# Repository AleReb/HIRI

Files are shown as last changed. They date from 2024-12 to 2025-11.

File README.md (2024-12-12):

# HIRI
"Proyecto HIRI usa ESP32 C3 para recolectar datos ambientales con PMS5003ST y transmitirlos vía BLE. Los datos se guardan en una SD. NeoPixel muestra estados y la pantalla OLED es solo para depuración. Monitorea batería y entra en deep sleep si es necesario. Diseñado para proyectos IoT. se adjuntan el diseño del shield"
# Proyecto HIRI usando BLE - Versión 0.02

## Descripción
Este proyecto utiliza un **ESP32 C3** para recolectar datos de un sensor **Plantower PMS5003ST** y transmitirlos vía BLE. Además, incorpora una pantalla OLED para depuración y un NeoPixel para indicadores visuales. Los datos se guardan en una tarjeta SD en formato CSV para facilitar su análisis.

## Características principales

1. **Comunicación BLE**:
   - Recepción de datos de latitud y longitud desde una aplicación móvil vía BLE.
   - Envío de datos del sensor al dispositivo móvil conectado.

2. **Gestión de Datos**:
   - Almacenamiento en una tarjeta SD en formato CSV.
   - Identificación única de sesiones usando timestamps.

3. **Indicadores visuales**:
   - **NeoPixel** para estados BLE:
   - azul para el inicio.
   - violeta para error.
   - cambia de verde a rojo segun el material particulado (segun norma chilena siendo 50ppm el nivel peligroso).
   - parpadea 3 veces si esta desconetado.
   - cuando guarda en la micro sd se atenua la luz un poco.
     
   - **OLED** para mostrar información de depuración como voltaje de batería, estado BLE, y valores de los sensores.

4. **Gestión de batería**:
   - Monitoreo del voltaje de la batería.
   - Entrada en modo deep sleep si el voltaje es inferior al umbral.

5. **Gestión de versiones**:
   - Registro de cambios y versiones en el encabezado del código.

6. **Tabla de IDs predefinidos**:
   - Asociación de IDs de dispositivo con datos predefinidos.

## Requisitos

### Hardware
- **ESP32 C3**
- Sensor **Plantower PMS5003ST**
- Pantalla OLED con interfaz I2C
- NeoPixel
- Tarjeta SD y lector compatible
- Fuente de alimentación con monitoreo de voltaje

### Librerías
Incluye las siguientes librerías en tu entorno de desarrollo (Arduino IDE o equivalente usando la placa esp32 c3 dev con la version 2.0.17 de la gestion de placas):

- `Adafruit_NeoPixel`
- `esp_adc_cal`
- `SoftwareSerial`
- `Wire`
- `SPI`
- `SD`
- `U8g2lib`
- `TimeLib`
- `BLEDevice`

## Instalación

1. **Clonar el repositorio**:
   ```bash
   git clone https://github.com/tu-usuario/proyecto-hiri.git
   cd proyecto-hiri
   ```

2. **Configurar el entorno de desarrollo**:
   - Abre el archivo principal en tu IDE.
   - Configura los pines según tu hardware.

3. **Carga del código**:
   - Conecta el ESP32 C3 a tu computadora.
   - Carga el código al ESP32 C3 desde tu IDE.

## Uso

1. Conecta la fuente de alimentación al ESP32 C3.
2. Abre la aplicación móvil para interactuar con el dispositivo vía BLE.
3. Observa el estado de conexión y los datos en la pantalla OLED.
4. Los datos recolectados se guardarán automáticamente en la tarjeta SD.

## Contribuir

1. Realiza un fork del proyecto.
2. Crea una nueva rama para tu característica o corrección de error:
   ```bash
   git checkout -b nueva-caracteristica
   ```
3. Haz commit de tus cambios:
   ```bash
   git commit -m "Añadida nueva característica"
   ```
4. Envía tus cambios:
   ```bash
   git push origin nueva-caracteristica
   ```
5. Abre un Pull Request en el repositorio principal.

## Licencia
Este proyecto está licenciado bajo la Licencia MIT. Consulta el archivo `LICENSE` para más detalles.

## Contacto
Si tienes preguntas o sugerencias, no dudes en contactar a:
**Alejandro Rebolledo. arebolledo@udd.cl**

## Registro de Cambios

### Versión 0.02.1
- Ajustes en la lógica de guardado de datos.
- Implementación de recepción de datos BLE (latitud, longitud, etc.).
- Mejoras en los indicadores NeoPixel y mensajes OLED.

### TO DO
- Mejorar la gestion y registro de dispostivos.
- Mejorar la forma de guardar los datos en el csv.

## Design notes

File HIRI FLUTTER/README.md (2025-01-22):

# hiri

Hiri app for device communication and configuration using BLE

## Getting Started

This project is a starting point for a Flutter application.

A few resources to get you started if this is your first Flutter project:

- [Lab: Write your first Flutter app](https://docs.flutter.dev/get-started/codelab)
- [Cookbook: Useful Flutter samples](https://docs.flutter.dev/cookbook)

For help getting started with Flutter development, view the
[online documentation](https://docs.flutter.dev/), which offers tutorials,
samples, guidance on mobile development, and a full API reference.

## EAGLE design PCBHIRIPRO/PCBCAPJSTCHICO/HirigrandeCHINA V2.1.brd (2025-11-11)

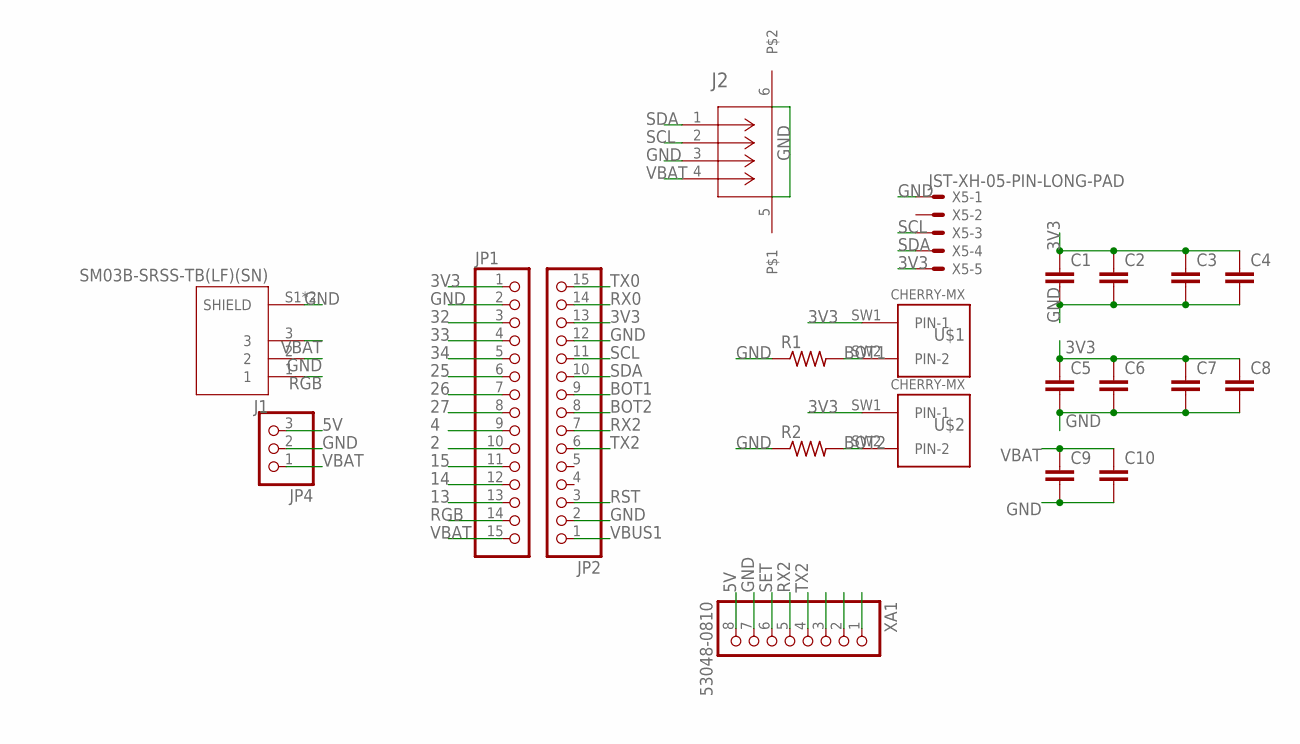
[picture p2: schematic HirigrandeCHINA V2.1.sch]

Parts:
C1, C2, C3, C4, C5, C6, C7, C8, C9, C10: C-EUC4532; C4532
J1: SM03B-SRSS-TB(LF)(SN); JST_SM03B-SRSS-TB(LF)(SN)
J2: SM04B-SRSS-TB; CONN_SM04B-SRSS-TB_JST
JP1, JP2: PINHD-1X15; 1X15
JP4: PINHD-1X3; 1X03
R1, R2: R-US_0204/7; 0204/7
U$1, U$2: CHERRY-MX
X5: JST-XH-05-PIN-LONG-PAD; JST-XH-05-PACKAGE-LONG-PAD
XA1: 53048-0810; MOLEX_53048-0810

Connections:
2: JP1.10
3V3: C1.1, C2.1, C3.1, C4.1, C5.1, C6.1, C7.1, C8.1, JP1.1, JP2.13, U$1.SW1 (PIN-1), U$2.SW1 (PIN-1), X5.5
4: JP1.9
5V: JP4.3, XA1.8
13: JP1.13
14: JP1.12
15: JP1.11
25: JP1.6
26: JP1.7
27: JP1.8
32: JP1.3
33: JP1.4
34: JP1.5
BOT1: JP2.9, R1.2, U$1.SW2 (PIN-2)
BOT2: JP2.8, R2.2, U$2.SW2 (PIN-2)
GND: C1.2, C2.2, C3.2, C4.2, C5.2, C6.2, C7.2, C8.2, C9.2, C10.2, J1.2, J1.S1 (SHIELD), J1.S2 (SHIELD), J2.3, J2.5, J2.6, JP1.2, JP2.2, JP2.12, JP4.2, R1.1, R2.1, X5.1, XA1.7
RGB: J1.1, JP1.14
RST: JP2.3
RX0: JP2.14
RX2: JP2.7, XA1.5
SCL: J2.2, JP2.11, X5.3
SDA: J2.1, JP2.10, X5.4
SET: XA1.6
TX0: JP2.15
TX2: JP2.6, XA1.4
VBAT: C9.1, C10.1, J1.3, J2.4, JP1.15, JP4.1
VBUS1: JP2.1

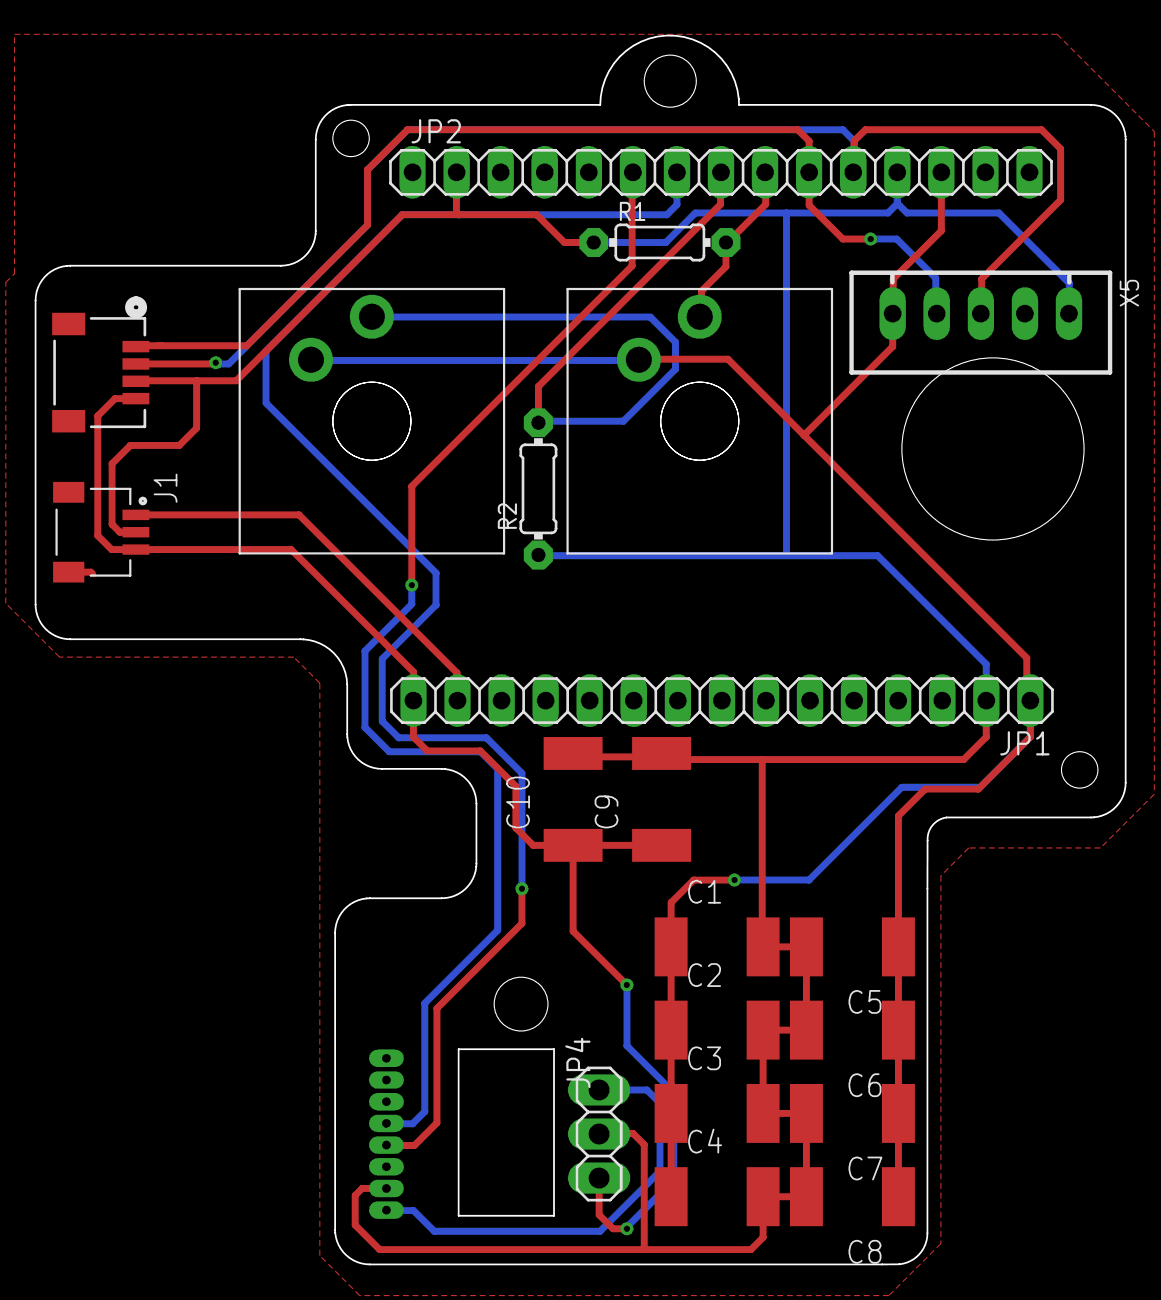
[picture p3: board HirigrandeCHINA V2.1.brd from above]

Board: 2 copper layers, 62.8 x 70.8 mm, 21 parts (0 on the bottom side), 11 nets.

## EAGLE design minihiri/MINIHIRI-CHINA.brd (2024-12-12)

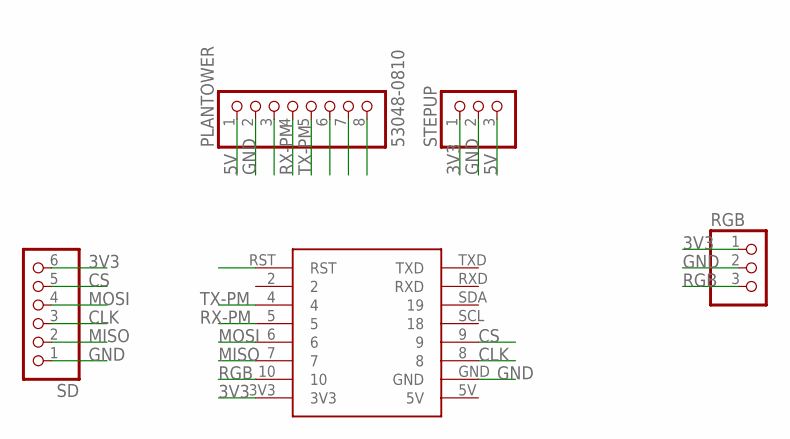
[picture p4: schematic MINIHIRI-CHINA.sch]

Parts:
PLANTOWER: 53048-0810; MOLEX_53048-0810
RGB: PINHD-1X3; 1X03
SD: PINHD-1X6; 1X06
STEPUP: PINHD-1X3; 1X03
U$2: LILYGOPLUSMINI; LILYGO-PADS

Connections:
3V3: RGB.1, SD.6, STEPUP.1, U$2.3V3
5V: PLANTOWER.1, STEPUP.3
CLK: SD.3, U$2.8
CS: SD.5, U$2.9
GND: PLANTOWER.2, RGB.2, SD.1, STEPUP.2, U$2.GND
MISO: SD.2, U$2.7
MOSI: SD.4, U$2.6
RGB: RGB.3, U$2.10
RX-PM: PLANTOWER.4, U$2.5
TX-PM: PLANTOWER.5, U$2.4

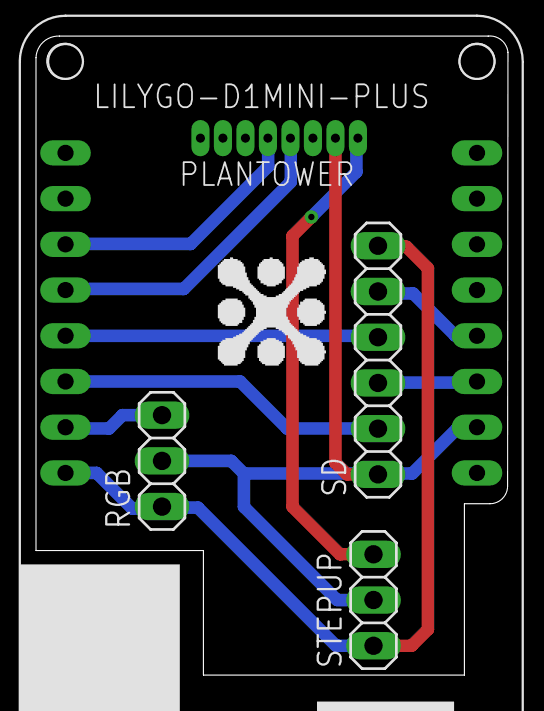
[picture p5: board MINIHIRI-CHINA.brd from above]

Board: 2 copper layers, 26.2 x 35.5 mm, 5 parts (0 on the bottom side), 10 nets.

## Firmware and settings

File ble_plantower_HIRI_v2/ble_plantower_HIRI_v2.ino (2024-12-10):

/* 
  Proyecto HIRI usando BLE - Versión 0.02
  Descripción:
  Este proyecto utiliza un ESP32 C3  para recolectar datos del sensor plantower 5003st y transmitirlos vía BLE.
  También incluye una pantalla OLED para mostrar información (solo para debug) y un NeoPixel para indicadores visuales.
  
  Cambios a Implementar:
  
  1. **Comunicación BLE:**
     - Implementar la recepción de datos de latitud y longitud desde una app móvil. Estos datos serán enviados vía BLE
       y serán utilizados para ubicar la posición geográfica del dispositivo.

  2. **Gestión de Datos y SD:**
     - Cambiar la forma de guardar los datos:
       - Utilizar un archivo CSV para registrar los datos de cada sesión, incluyendo una estructura clara para 
         poder procesarlos posteriormente (tiempo, voltaje, PM2.5, temperatura, humedad, coordenadas GPS, estado BLE, etc.).
       - Guardar la sesión con un nombre diferente si el dispositivo está "conectado" o "no conectado". 
       - Incluir una lógica para diferenciar entre sesiones (por ejemplo, usando el timestamp como parte del nombre del archivo).
  
  3. **Indicador de Conexión BLE:**
     - Implementar un sistema de indicadores claros para el estado de conexión BLE:
       - Utilizar el NeoPixel para indicar cuando el dispositivo está conectado (verde) o no (rojo).
       - En la pantalla OLED, mostrar si la conexión BLE está activa.

  4. **Gestión de Versiones:**
     - Incluir un sistema de gestión de versiones en el encabezado del archivo, que registre cada cambio importante, incluyendo:
       - Versión del firmware.
       - Fecha y autor de la modificación.
       - Descripción de los cambios realizados.
  
  5. **Tareas Adicionales:**
     - Gestionar los datos de consumo de batería y entrar en modo deep sleep cuando la batería esté por debajo de un umbral seguro.
     - Implementar cambios para indicar si el dispositivo está "conectado" o "desconectado" durante la sesión y 
       guardar estos estados de forma clara en el archivo CSV.

  Fecha: 11/09/2024
  Autor: Alejandro Rebolledo D.
  Fecha: 12/12/2024
  se han hecho cambios en la respuesta del mensaje, el primer mensaje sera el de los datos del sensor estos se hicieron manualmente en el registro de una tabla
  adjunto en la pestaña a demas de gestionar de mejor manera los datos en la microsd
*/
/*
tabla del primer dato para hacer guardado con la app
HIRI-01	 7	25:3,25:6,25:8,28:4,29:11,29:12
HIRI-02	 8	26:3,26:6,26:8,30:4,31:11,31:12
HIRI-03  9	27:3,27:6,27:8,32:4,33:11,33:12
HIRI-04	10	35:3,35:6,35:8,34:4,36:11,36:12
HIRI-05	11	38:3,38:6,38:8,37:4,39:11,39:12
HIRI-06	12	41:3,41:6,41:8,40:4,42:11,42:12
HIRI-07	13	44:3,44:6,44:8,43:4,45:11,45:12
HIRI-08	14	47:3,47:6,47:8,46:4,48:11,48:12
HIRI-09	15	50:3,50:6,50:8,49:4,51:11,51:12
HIRI-10	16	53:3,53:6,53:8,52:4,54:11,54:12
HIRI-11	17	56:3,56:6,56:8,55:4,57:11,57:12
HIRI-12	18	59:3,59:6,59:8,58:4,60:11,60:12
HIRI-13	19	62:3,62:6,62:8,61:4,63:11,63:12
HIRI-14	20	65:3,65:6,65:8,64:4,66:11,66:12
HIRI-15	21	68:3,68:6,68:8,67:4,69:11,69:12
*/

// Incluye las librerías necesarias
#include <Adafruit_NeoPixel.h>
#include "esp_adc_cal.h"
#include <SoftwareSerial.h>
#include <Wire.h>
#include <SPI.h>
#include <SD.h>
#include <U8g2lib.h>
#include <TimeLib.h>

// Definición de variables globales
String fecha;
String horas;

// Función para actualizar las variables globales con la fecha
void actualizarFecha() {
  char bufferFecha[11];
  sprintf(bufferFecha, "%02d/%02d/%04d", day(), month(), year());
  fecha = String(bufferFecha);
}

// Función para actualizar las variables globales con la hora
void actualizarHora() {
  char bufferHora[9];
  sprintf(bufferHora, "%02d:%02d:%02d", hour(), minute(), second());
  horas = String(bufferHora);
}
// Librerías BLE
#include <BLEDevice.h>
#include <BLEUtils.h>
#include <BLEServer.h>

// Variable para indicar el estado de conexión BLE
bool deviceConnected = false;

// Clase de callbacks para manejar la conexión y desconexión BLE
class MyServerCallbacks : public BLEServerCallbacks {
  void onConnect(BLEServer *pServer) {
    deviceConnected = true;
    Serial.println("Dispositivo BLE conectado");
  }

  void onDisconnect(BLEServer *pServer) {
    deviceConnected = false;
    Serial.println("Dispositivo BLE desconectado");
    // Reiniciar la publicidad para permitir nuevas conexiones
    pServer->getAdvertising()->start();
  }
};

// Definición de pines
#define BAT_ADC 2  // Pin ADC para medir voltaje de batería

// Configuración de SoftwareSerial para el sensor PMS5003
#define RX 4
#define TX 5
SoftwareSerial pms5(RX, TX);  // RX, TX

// Configuración de NeoPixel
#define NEOPIXEL_PIN 10
#define NUMPIXELS 1
Adafruit_NeoPixel pixels(NUMPIXELS, NEOPIXEL_PIN, NEO_GRB + NEO_KHZ800);

// Pines I2C
#define SDA 18
#define SCL 19

// Pines para la tarjeta SD
#define SD_MISO 7
#define SD_MOSI 6
#define SD_SCLK 8
#define SD_CS_PIN 9


// Inicializar la pantalla
U8G2_SH1106_128X32_VISIONOX_F_HW_I2C u8g2(U8G2_R0, /* reset=*/U8X8_PIN_NONE);

// Variables para medición de voltaje de batería
float Voltage = 0.0;
float batteryVoltage = 0.0;
esp_adc_cal_characteristics_t adc_chars;
float lowBat = 3.45;  // Umbral de voltaje bajo de batería

// Variables para datos del sensor
unsigned int PMS2_5 = 0, PMS1 = 0, PMS10 = 0, TPS = 0, HDS = 0;
unsigned char bufferRTT[32] = {};  // Datos recibidos por Serial

// Variables de tiempo
unsigned long checkpms = 0;                // Última lectura de datos del sensor
const unsigned long intercheckpms = 5000;  // Intervalo entre lecturas (milisegundos)

// Disponibilidad de la tarjeta SD
bool sd_available = false;
SPIClass spiSD(SPI);

// Variables BLE
#define VERSION "V0.02.1"
#define DEVICE_NAME "HIRI-11" /////////////////////////// cambiar segun el numero de dispositivo ya esta cargada la configuracion del primer mensaje segun la tabla
String dataLOG = "/" + String(DEVICE_NAME) + ".csv";
String id = DEVICE_NAME;

bool firstConect = true;
bool callbackRecivido = false;
// UUIDs para el servicio BLE y características
#define SERVICE_UUID "4fafc201-1fb5-459e-8fcc-c5c9c331914b"
#define CHAR_UUID_TX "beb5483e-36e1-4688-b7f5-ea07361b26a8"  // Para enviar datos
#define CHAR_UUID_RX "6e400003-b5a3-f393-e0a9-e50e24dcca9e"  // Para recibir datos

BLECharacteristic *pTxCharacteristic;
BLECharacteristic *pRxCharacteristic;

// Buffer para mensajes recibidos por BLE
String receivedMessage = "";
// Variables para el manejo de recepcion de datos
String latitud;     // Position 1 -- code
String longitud;    // Position 2 -- code
String timestamp;   // timestamp
String sesionID;    // sensionID
String notaEVento;  // eventos especiales
// Callback BLE para recibir datos


// Function to split the string by a delimiter and get the value at a specified index
String getValor(String data, char separator, int index) {
  int found = 0;                     // Tracks how many substrings we have found
  int strIndex[] = { 0, -1 };        // Array to store the start and end indices of the substring
  int maxIndex = data.length() - 1;  // Last index of the string

  // Loop through the string to find substrings separated by the delimiter
  for (int i = 0; i <= maxIndex && found <= index; i++) {
    if (data.charAt(i) == separator || i == maxIndex) {
      found++;
      strIndex[0] = strIndex[1] + 1;
      strIndex[1] = (i == maxIndex) ? i + 1 : i;
    }
  }

  // If the required index was found, return the substring, otherwise return an empty string
  return found > index ? data.substring(strIndex[0], strIndex[1]) : "";
}

class MyCallbacks : public BLECharacteristicCallbacks {
  void onWrite(BLECharacteristic *pCharacteristic) {
    std::string rxValue = pCharacteristic->getValue();
    if (rxValue.length() > 0) {
      receivedMessage = String(rxValue.c_str());       // dato recibido
      latitud = getValor(receivedMessage, ',', 0);     // dato sacado con la funcion para separar por comas
      longitud = getValor(receivedMessage, ',', 1);    // dato sacado
      timestamp = getValor(receivedMessage, ',', 2);   // dato sacado
      sesionID = getValor(receivedMessage, ',', 3);    // dato sacado
      notaEVento = getValor(receivedMessage, ',', 4);  // dato sacado
      Serial.println("Recibido por BLE: " + receivedMessage);
      if (receivedMessage == "OK") {
        Serial.println("RECIBI OK DESDE LA APP");
        callbackRecivido = true;
      }
      Serial.println("Latitud: " + latitud);
      Serial.println("Longitud: " + longitud);
      Serial.println("Timestamp: " + timestamp);
      Serial.println("SesionID: " + sesionID);
      Serial.println("Evento: " + notaEVento);
      // Convierte el timestamp a un entero largo (long)
      unsigned long unixTimestamp = timestamp.toInt();
      // Usa la función setTime para establecer la hora basada en el timestamp UNIX
      setTime(unixTimestamp);
      // Actualiza las variables globales con la fecha y hora actuales
      actualizarFecha();
      actualizarHora();
      // Imprime las variables globales
      Serial.print("Fecha: ");
      Serial.println(fecha);
      Serial.print("Hora: ");
      Serial.println(horas);
    }
  }
};

uint32_t readADC_Cal(int ADC_Raw) {
  return esp_adc_cal_raw_to_voltage(ADC_Raw, &adc_chars);
}

// Variables para el consumo de batería
const float AVERAGE_CURRENT_MA = 148.0;  // Corriente promedio en mA
unsigned long startMillis;               // Tiempo de inicio en milisegundos
float consumed_mAh = 0.0;                // Energía consumida en mAh

// Tiempo de funcionamiento
unsigned long currentMillis;
unsigned long elapsedMillis;
int seg = 0;
int minu = 0;
int hora = 0;

// Variables para el parpadeo del LED
bool ledState = false;
unsigned long previousMillis = 0;
const long interval = 500;  // Intervalo de parpadeo en milisegundos

// Variables para el parpadeo cuando no está conectado
unsigned long lastBlinkTime = 0;
unsigned long blinkInterval = 200;  // Duración del estado encendido/apagado del LED durante el parpadeo (en ms)
int blinkCount = 0;
int totalBlinks = 3;  // Número total de parpadeos
bool isBlinking = false;
unsigned long lastBlinkSequenceTime = 0;
unsigned long blinkSequenceInterval = 20000;  // Intervalo entre secuencias de parpadeo (en ms)

// Variables para manejo de la pantalla
bool displayDataSaved = false;
unsigned long dataSavedTime = 0;
const unsigned long dataSavedDisplayTime = 2000;  // Mostrar "Data saved" por 2 segundos



void fadeEffect(uint32_t originalColor) {
  for (int i = 255; i >= 0; i -= 15) {
    uint8_t r = (originalColor >> 16) & 0xFF;
    uint8_t g = (originalColor >> 8) & 0xFF;
    uint8_t b = originalColor & 0xFF;
    pixels.setPixelColor(0, pixels.Color((r * i) / 255, (g * i) / 255, (b * i) / 255));
    pixels.show();
    delay(20);
  }

  // Restaurar el color original
  pixels.setPixelColor(0, originalColor);
  pixels.show();
}

void setup() {
  // Inicializar Serial
  Serial.begin(115200);
  // Inicializar NeoPixel
  pixels.begin();
  // Inicializar LED a color azul durante el inicio
  pixels.setPixelColor(0, pixels.Color(0, 0, 255));  // Azul
  pixels.show();

  // Inicializar I2C
  Wire.begin(SDA, SCL);

  // Inicializar pantalla
  u8g2.begin();

  // Inicializar medición de voltaje de batería
  esp_adc_cal_characterize(ADC_UNIT_1, ADC_ATTEN_DB_11, ADC_WIDTH_BIT_12, 1100, &adc_chars);

  // Inicializar SPI para tarjeta SD
  spiSD.begin(SD_SCLK, SD_MISO, SD_MOSI, SD_CS_PIN);

  if (!SD.begin(SD_CS_PIN, spiSD)) {
    // Error al inicializar la tarjeta SD
    sd_available = false;
    Serial.println("¡Error al inicializar la tarjeta SD!");
    // Mostrar mensaje en OLED
    u8g2.clearBuffer();
    u8g2.setFont(u8g2_font_5x7_tr);
    u8g2.drawStr(0, 8, "SD no encontrada");
    u8g2.sendBuffer();
    // Cambiar color del LED a morado para indicar error en SD
    pixels.setPixelColor(0, pixels.Color(128, 0, 128));  // Morado
    pixels.show();
  } else {
    sd_available = true;
    Serial.println("Tarjeta SD inicializada.");
    // Mostrar mensaje en OLED
    u8g2.clearBuffer();
    u8g2.setFont(u8g2_font_5x7_tr);
    u8g2.drawStr(0, 8, "SD encontrada");
    u8g2.sendBuffer();
    // Cambiar color del LED a verde para indicar SD correcta
    pixels.setPixelColor(0, pixels.Color(0, 255, 0));  // Verde
    pixels.show();
  }

  // Inicializar SoftwareSerial para el sensor PMS
  pms5.begin(9600);

  // Inicializar BLE
  Serial.println("Iniciando BLE...");
  BLEDevice::init(DEVICE_NAME);
  BLEServer *pServer = BLEDevice::createServer();

  // Asignar los callbacks para el estado de conexión
  pServer->setCallbacks(new MyServerCallbacks());

  // Crear servicio BLE
  BLEService *pService = pServer->createService(SERVICE_UUID);

  // Crear características BLE
  pTxCharacteristic = pService->createCharacteristic(
    CHAR_UUID_TX,
    BLECharacteristic::PROPERTY_NOTIFY | BLECharacteristic::PROPERTY_READ  // Conservado según lo solicitado
  );

  pRxCharacteristic = pService->createCharacteristic(
    CHAR_UUID_RX,
    BLECharacteristic::PROPERTY_WRITE);

  pRxCharacteristic->setCallbacks(new MyCallbacks());

  // Iniciar el servicio
  pService->start();

  // Iniciar publicidad
  BLEAdvertising *pAdvertising = BLEDevice::getAdvertising();
  pAdvertising->addServiceUUID(SERVICE_UUID);
  pAdvertising->setScanResponse(true);
  pAdvertising->setMinPreferred(0x06);  // Ayuda con problemas de conexión en iPhone
  pAdvertising->setMinPreferred(0x12);
  BLEDevice::startAdvertising();
  Serial.println("¡Característica definida! Ahora puedes leerla en tu teléfono.");
  String data = getDataById(id);
  if (data != "") {
    Serial.println("Datos encontrados para " + id + ": " + data);
    // Aquí puede agregar el código para enviar 'data' por BLE
  } else {
    Serial.println("ID no encontrado.");
  }
  // Inicializar el tiempo de inicio
  startMillis = millis();
}

void loop() {
  // Actualizar el tiempo de funcionamiento
  currentMillis = millis();
  elapsedMillis = currentMillis - startMillis;

  // Calcular horas, minutos y segundos
  seg = (elapsedMillis / 1000) % 60;
  minu = (elapsedMillis / (1000 * 60)) % 60;
  hora = (elapsedMillis / (1000 * 60 * 60));

  // Control del LED según el estado de conexión BLE
  if (deviceConnected) {
    // BLE conectado: LED encendido con color sólido según PM2.5
    uint8_t redValue, greenValue;
    if (PMS2_5 <= 50) {
      redValue = map(PMS2_5, 0, 50, 0, 255);
      greenValue = map(PMS2_5, 0, 50, 255, 0);
    } else {
      redValue = 255;
      greenValue = 0;
    }
    pixels.setPixelColor(0, pixels.Color(redValue, greenValue, 0));
    pixels.show();

    // Reiniciar variables de parpadeo
    isBlinking = false;
    blinkCount = 0;
  } else {
    // BLE no conectado: parpadeo 5 veces cada 10 segundos y luego volver al estado de indicar MP
    handleDisconnectionBlinking();
  }

  // Mostrar datos en la pantalla
  displayData();

  // Lectura de sensores cada 5 segundos
  if (millis() - checkpms >= intercheckpms) {
    checkpms = millis();

    // Leer datos del sensor PMS
    if (pms5.available() > 0) {
      readPMSSensor();
    }

    // Leer voltaje de batería
    Voltage = (readADC_Cal(analogRead(BAT_ADC))) * 2;  // Ajustar si se usa un divisor de voltaje
    batteryVoltage = Voltage / 1000.0;

    // Si el voltaje es menor que el umbral, entrar en deep sleep
    if (batteryVoltage < lowBat) {
      // Parpadear NeoPixel en rojo 3 veces antes de entrar en deep sleep
      for (int i = 0; i < 3; i++) {
        pixels.setPixelColor(0, pixels.Color(255, 0, 0));  // Rojo
        pixels.show();
        delay(500);
        pixels.setPixelColor(0, pixels.Color(0, 0, 0));  // Apagar
        pixels.show();
        delay(500);
      }
      u8g2.setPowerSave(1);
      // Entrar en modo Deep Sleep
      Serial.println("Voltaje demasiado bajo, entrando en deep sleep...");
      esp_deep_sleep_start();
    }

    // Guardar los datos en la tarjeta SD
    if (sd_available) {
      // Crear un string con toda la información que deseas guardar
      String dataString = "Tiempo: " + String(millis()) + ", Latitud: " + latitud + ", Longitud: " + longitud + ", Timestamp: " + timestamp + ", SesionID: " + sesionID + ", Evento: " + notaEVento + ", Fecha: " + fecha + ", Hora: " + horas + ", Bat: " + String(batteryVoltage, 2) + "V" + ", PM2.5: " + String(PMS2_5) + " ug/m3" + ", Temp: " + String(TPS / 10) + "." + String(TPS % 10) + "C" + ", Hum: " + String(HDS / 10) + "." + String(HDS % 10) + "%";
      File dataFile = SD.open(dataLOG, FILE_APPEND);
      // Realizar el efecto de "bajada de luz" tras guardar datos
      if (dataFile) {
        dataFile.println(dataString);  // Escribe la cadena en el archivo
        dataFile.close();
        Serial.println("Guardado en SD: " + dataString);  // Imprime la cadena en la consola

        uint32_t currentColor = pixels.getPixelColor(0);  // Obtener el color actual del LED
        fadeEffect(currentColor);                         // Llamada a la función para el efecto de atenuación
        // Resetea todas las variables a strings vacíos para esperar nuevos datos
        latitud = "";
        longitud = "";
        timestamp = "";
        sesionID = "";
        notaEVento = "";
        fecha = "";
        horas = "";
        // Mostrar mensaje de datos guardados en pantalla
        displayDataSaved = true;
        dataSavedTime = millis();
      } else {
        // Error al abrir el archivo
        Serial.println("Error al abrir: " + dataLOG);
        // Cambiar color del LED a rojo para indicar error al guardar en SD
        pixels.setPixelColor(0, pixels.Color(255, 0, 0));  // Rojo
        pixels.show();
      }
    }

    // Enviar datos por BLE si está conectado
    if (deviceConnected) {
      Serial.println("Conectado: " + String(deviceConnected));
      if (firstConect == true) {
        String data = getDataById(id);
        if (data != "") {
          Serial.println("Datos encontrados para " + id + ": " + data);
          // Aquí puede agregar el código para enviar 'data' por BLE
        } else {
          Serial.println("ID no encontrado.");
        }
        pTxCharacteristic->setValue(data.c_str());
        pTxCharacteristic->notify();
        Serial.println("Enviado por BLE: " + data);
        if (callbackRecivido == true) {
          Serial.println("Recibido OK");
          firstConect = false;
        }
      } else {
        String data = String(PMS2_5) + "," + id + "," + String(HDS) + "," + String(TPS) + "," + String(batteryVoltage);
        pTxCharacteristic->setValue(data.c_str());
        pTxCharacteristic->notify();
        Serial.println("Enviado por BLE: " + data);
      }
    } else {
      Serial.println("no Conectado: " + String(deviceConnected));
      firstConect = true;
      callbackRecivido = false;
    }

    // Calcular el consumo de batería hasta este punto
    unsigned long currentMillisCC = millis();
    float elapsedHours = (currentMillisCC - startMillis) / 3600000.0;
    consumed_mAh = AVERAGE_CURRENT_MA * elapsedHours;

    // Salidas seriales con los datos del sensor y los datos guardados
    Serial.println("-----------------------Datos--------------------------");
    Serial.printf("Voltaje de Batería: %.2fV\n", batteryVoltage);
    Serial.printf("Temp: %d.%d C\n", TPS / 10, TPS % 10);
    Serial.printf("Humedad: %d.%d %%\n", HDS / 10, HDS % 10);
    Serial.printf("PM1.0: %u ug/m3\n", PMS1);
    Serial.printf("PM2.5: %u ug/m3\n", PMS2_5);
    Serial.printf("PM10: %u ug/m3\n", PMS10);
    Serial.printf("Energía Consumida: %.2f mAh\n", consumed_mAh);
    Serial.printf("Tiempo de Funcionamiento: %d:%02d:%02d\n", hora, minu, seg);
  }

  // Si se recibió un mensaje BLE, se mostrará en displayData()
}

void readPMSSensor() {
  while (pms5.available() > 0) {
    for (int i = 0; i < 32; i++) {
      bufferRTT[i] = (char)pms5.read();
      delay(2);
    }

    pms5.flush();

    unsigned int CR1 = (bufferRTT[30] << 8) + bufferRTT[31];
    unsigned int CR2 = 0;
    for (int i = 0; i < 30; i++)
      CR2 += bufferRTT[i];

    if (CR1 == CR2) {
      PMS1 = (bufferRTT[10] << 8) + bufferRTT[11];    // PM1.0
      PMS2_5 = (bufferRTT[12] << 8) + bufferRTT[13];  // PM2.5
      PMS10 = (bufferRTT[14] << 8) + bufferRTT[15];   // PM10
      TPS = (bufferRTT[24] << 8) + bufferRTT[25];     // Temperatura
      HDS = (bufferRTT[26] << 8) + bufferRTT[27];     // Humedad
    }
  }
}

void displayData() {
  u8g2.clearBuffer();
  u8g2.setFont(u8g2_font_5x8_tr);
  char buf[20];
  sprintf(buf, "Bat: %.2fV", batteryVoltage);
  u8g2.drawStr(0, 8, buf);
  if (receivedMessage.length() > 0) {
    // Mostrar mensaje recibido
    u8g2.drawStr(60, 8, receivedMessage.c_str());
  } else {
    u8g2.drawStr(60, 8, String(consumed_mAh).c_str());
  }

  sprintf(buf, "PM2.5: %u", PMS2_5);
  u8g2.drawStr(0, 16, buf);
  u8g2.drawStr(60, 16, id.c_str());

  sprintf(buf, "Temp: %d.%dC", TPS / 10, TPS % 10);
  u8g2.drawStr(0, 24, buf);

  sprintf(buf, "Hum: %d.%d%%", HDS / 10, HDS % 10);
  u8g2.drawStr(60, 24, buf);

  // Mostrar tiempo de funcionamiento
  sprintf(buf, "%d:%02d:%02d", hora, minu, seg);
  u8g2.drawStr(0, 32, buf);

  if (displayDataSaved) {
    // Mostrar mensaje de datos guardados
    u8g2.drawStr(60, 32, "Data saved");
    // Verificar si han pasado 2 segundos para ocultar el mensaje
    if (millis() - dataSavedTime >= dataSavedDisplayTime) {
      receivedMessage = "";
      displayDataSaved = false;
    }
  } else {
    // Mostrar estado de conexión
    if (deviceConnected) {
      u8g2.drawStr(60, 32, "Connected");
    } else {
      u8g2.drawStr(60, 32, "Not Conn");
    }
  }

  u8g2.sendBuffer();
}
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

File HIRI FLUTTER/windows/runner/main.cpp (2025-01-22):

#include <flutter/dart_project.h>
#include <flutter/flutter_view_controller.h>
#include <windows.h>

#include "flutter_window.h"
#include "utils.h"

int APIENTRY wWinMain(_In_ HINSTANCE instance, _In_opt_ HINSTANCE prev,
                      _In_ wchar_t *command_line, _In_ int show_command) {
  // Attach to console when present (e.g., 'flutter run') or create a
  // new console when running with a debugger.
  if (!::AttachConsole(ATTACH_PARENT_PROCESS) && ::IsDebuggerPresent()) {
    CreateAndAttachConsole();
  }

  // Initialize COM, so that it is available for use in the library and/or
  // plugins.
  ::CoInitializeEx(nullptr, COINIT_APARTMENTTHREADED);

  flutter::DartProject project(L"data");

  std::vector<std::string> command_line_arguments =
      GetCommandLineArguments();

  project.set_dart_entrypoint_arguments(std::move(command_line_arguments));

  FlutterWindow window(project);
  Win32Window::Point origin(10, 10);
  Win32Window::Size size(1280, 720);
  if (!window.Create(L"hiri", origin, size)) {
    return EXIT_FAILURE;
  }
  window.SetQuitOnClose(true);

  ::MSG msg;
  while (::GetMessage(&msg, nullptr, 0, 0)) {
    ::TranslateMessage(&msg);
    ::DispatchMessage(&msg);
  }

  ::CoUninitialize();
  return EXIT_SUCCESS;
}

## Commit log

2025-01-22 se agrega el flutter echo por simon arias
    en un intento de seguir desarrollando la aps se hace la transferencia
2025-11-11 Add initial README with PCB information
2025-11-11 Rename PCBHIRIPRO/HirigrandeCHINA V2.1.brd to PCBHIRIPRO/PCBCAPJSTCHICO/HirigrandeCHINA V2.1.brd
    make folder
    [HirigrandeCHINA V2.1.brd]
2025-11-11 Rename PCBHIRIPRO/HirigrandeCHINA V2.1.sch to PCBHIRIPRO/PCBCAPJSTCHICO/HirigrandeCHINA V2.1.sch
    [HirigrandeCHINA V2.1.sch]
